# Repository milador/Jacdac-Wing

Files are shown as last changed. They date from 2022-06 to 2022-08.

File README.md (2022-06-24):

# Jacdaptor-FeatherWing

## Top View: 

<p align="center">
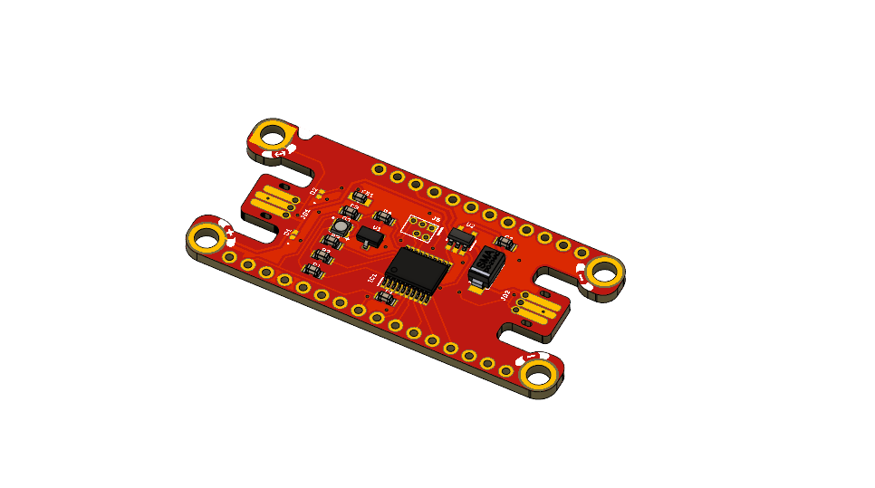
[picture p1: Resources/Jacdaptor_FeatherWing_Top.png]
Jacdaptor-FeatherWing Top

</p>

## Bottom View:

<p align="center">
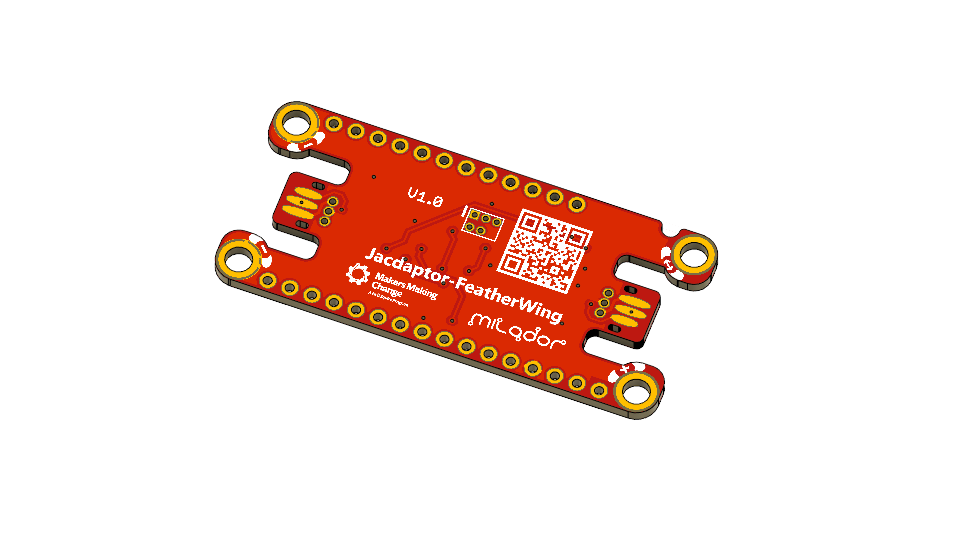
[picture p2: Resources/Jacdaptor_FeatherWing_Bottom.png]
Jacdaptor-FeatherWing Bottom

</p>

## Completed:

<p align="center">
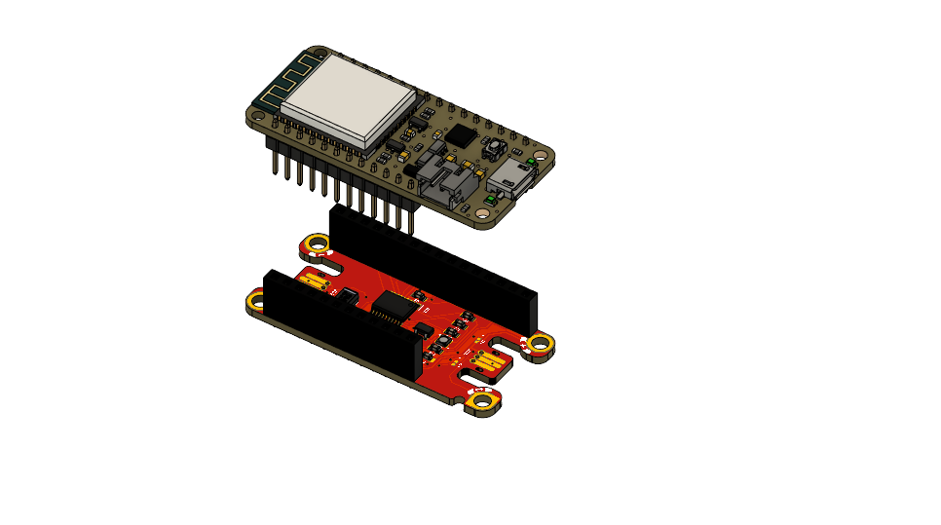
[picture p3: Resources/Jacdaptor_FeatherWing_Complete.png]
Jacdaptor FeatherWing Complete

</p>

<p align="center">
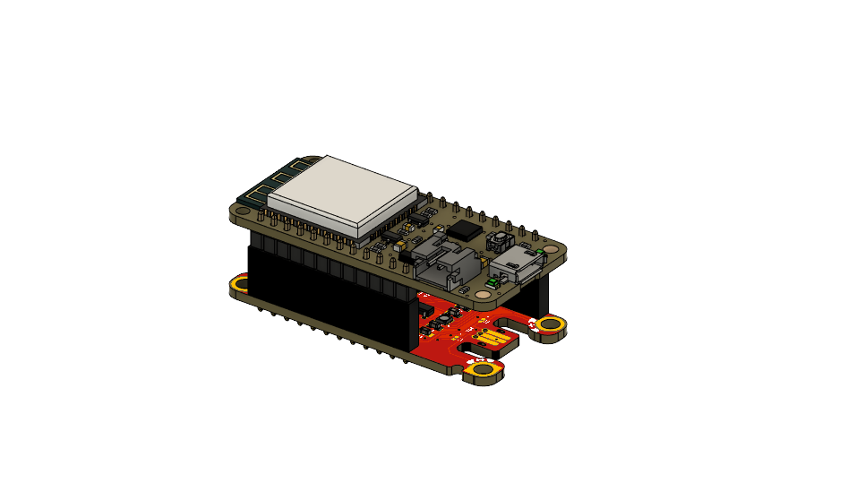
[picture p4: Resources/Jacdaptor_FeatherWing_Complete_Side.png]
Jacdaptor FeatherWing Complete Side

</p>

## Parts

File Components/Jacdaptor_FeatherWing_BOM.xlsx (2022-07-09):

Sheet: RevA
Index | Quantity | Item | Value | Digikey/Mouser/LCSC Part Number | Manufacturer Part Number | Description | Unit Price (CAD) | Total Price (CAD) | Link
1 | 2 | R1,R2 | 30R | C136965 | RT0603BRD0730RL | RES 30 OHM 1% 1/8W 0603 | 0.0344 | 0.0688 | https://lcsc.com/product-detail/Chip-span-style-background-color-ff0-Resistor-span-Surface-Mount_YAGEO-RT0603BRD0730RL_C136965.html
2 | 1 | R3 | 150R | C319859 | AR03BTCX1500 | RES 150 OHM 1% 1/8W 0603 | 0.037 | 0.037 | https://lcsc.com/product-detail/Chip-Resistor-Surface-Mount_Viking-Tech-AR03BTCX1500_C319859.html
3 | 1 | R4 | 220R | C318124 | AR03BTCX2200 | RES SMD 220 OHM 5% 1/8W 0603 | 0.029 | 0.029 | https://lcsc.com/product-detail/Chip-Resistor-Surface-Mount_Viking-Tech-AR03BTCX2200_C318124.html
4 | 1 | U1 | BAT54S,235 | C503463 | BAT54S,235 | DIODE ARRAY SCHOTTKY 30V SOT23 | 0.03 | 0.03 | https://lcsc.com/product-detail/Pre-ordered-transistors_Nexperia-BAT54S-235_C503463.html
5 | 1 | U2 | STM32G030F6P6 | C724040 | STM32G030F6P6 | IC MCU 32BIT 32KB FLASH 20TSSOP | 0.98 | 0.98 | https://lcsc.com/product-detail/ST-Microelectronics_STMicroelectronics-STM32G030F6P6_C724040.html
6 | 1 | U3 | APL3511DBI | C351148 | APL3511DBI-TRG | SOT-23-5 POWER DISTRIBUTION | 0.3 | 0.3 | https://lcsc.com/product-detail/Power-Distribution-Switches_Anpec-Elec-APL3511DBI-TRG_C351148.html
7 | 2 | C1,C2 | 4.7uF | C342959 | C1608X7S1A475KT000E | CAP CER 4.7UF 10V X5R 0603 | 0.048 | 0.096 | https://lcsc.com/product-detail/Multilayer-Ceramic-Capacitors-MLCC-SMD-SMT_TDK-C1608X7S1A475KT000E_C342959.html
8 | 1 | C3 | 33pF | C519485 | CC0603FRNPO9BN330 | CAP CER 0603 33PF 50V ULTRA STAB | 0.0177 | 0.0177 | https://lcsc.com/product-detail/Multilayer-Ceramic-Capacitors-MLCC-SMD-SMT_YAGEO-CC0603FRNPO9BN330_C519485.html
9 | 1 | FB1 | 800mA 1kR | C193411 | MPZ1608S102ATD25 | FERRITE BEAD 1 KOHM 0603 1LN | 0.028 | 0.028 | https://lcsc.com/product-detail/Ferrite-Beads_TDK-MPZ1608S102ATD25_C193411.html
10 | 2 | D1,D2 | RCLAMP0521P | C2827711 | RCLAMP0521P | TVS DIODE 5VWM 25VC SLP1006P2 | 0.0445 | 0.089 | https://lcsc.com/product-detail/ESD-Protection-Devices_TECH-PUBLIC-RCLAMP0521P_C2827711.html
11 | 1 | LED (D3) | RGB LED | 516-1795-1-ND /C97504 | HSMF-C114 | LED RGB DIFFUSED CHIP SMD | 2.63 | 2.63 | https://www.digikey.ca/en/products/detail/broadcom-limited/HSMF-C114/1235344 | https://lcsc.com/product-detail/Light-Emitting-Diodes-LED_Broadcom-Limited-HSMF-C114_C97504.html
12 | 1 | D4 | SCHOTTKY DIODE | C2480 | SS14 | SCHOTTKY DIODE | 0.0208 | 0.0208 | https://lcsc.com/product-detail/Schottky-Barrier-Diodes-SBD_MDD-Microdiode-Electronics-SS14_C2480.html
 |  |  |  |  |  |  | Total Price: | 4.3263

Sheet: RevB
Index | Quantity | Item | Value | Digikey/Mouser/LCSC Part Number | Manufacturer Part Number | Description | Unit Price (CAD) | Total Price (CAD) | Link
1 | 1 | R1 | 470R | C374403 | AR03BTC4700 | RES 470 OHM 0.1% 1/8W 0603 | 0.0316 | 0.0316 | https://lcsc.com/product-detail/Chip-Resistor-Surface-Mount_Viking-Tech-AR03BTC4700_C374403.html
2 | 1 | R3 | 150R | C319859 | AR03BTCX1500 | RES 150 OHM 1% 1/8W 0603 | 0.037 | 0.037 | https://lcsc.com/product-detail/Chip-Resistor-Surface-Mount_Viking-Tech-AR03BTCX1500_C319859.html
3 | 2 | R2,R4 | 220R | C318124 | AR03BTCX2200 | RES SMD 220 OHM 5% 1/8W 0603 | 0.029 | 0.058 | https://lcsc.com/product-detail/Chip-Resistor-Surface-Mount_Viking-Tech-AR03BTCX2200_C318124.html
4 | 1 | U1 | BAT54S,235 | C503463 | BAT54S,235 | DIODE ARRAY SCHOTTKY 30V SOT23 | 0.03 | 0.03 | https://lcsc.com/product-detail/Pre-ordered-transistors_Nexperia-BAT54S-235_C503463.html
5 | 1 | U2 | STM32G030F6P6 | C724040 | STM32G030F6P6 | IC MCU 32BIT 32KB FLASH 20TSSOP | 0.98 | 0.98 | https://lcsc.com/product-detail/ST-Microelectronics_STMicroelectronics-STM32G030F6P6_C724040.html
6 | 1 | U3 | APL3511DBI | C351148 | APL3511DBI-TRG | SOT-23-5 POWER DISTRIBUTION | 0.3 | 0.3 | https://lcsc.com/product-detail/Power-Distribution-Switches_Anpec-Elec-APL3511DBI-TRG_C351148.html
7 | 2 | C1,C2 | 4.7uF | C342959 | C1608X7S1A475KT000E | CAP CER 4.7UF 10V X5R 0603 | 0.048 | 0.096 | https://lcsc.com/product-detail/Multilayer-Ceramic-Capacitors-MLCC-SMD-SMT_TDK-C1608X7S1A475KT000E_C342959.html
8 | 1 | C3 | 33pF | C519485 | CC0603FRNPO9BN330 | CAP CER 0603 33PF 50V ULTRA STAB | 0.0177 | 0.0177 | https://lcsc.com/product-detail/Multilayer-Ceramic-Capacitors-MLCC-SMD-SMT_YAGEO-CC0603FRNPO9BN330_C519485.html
9 | 1 | FB1 | 800mA 1kR | C193411 | MPZ1608S102ATD25 | FERRITE BEAD 1 KOHM 0603 1LN | 0.028 | 0.028 | https://lcsc.com/product-detail/Ferrite-Beads_TDK-MPZ1608S102ATD25_C193411.html
10 | 2 | D1,D2 | RCLAMP0521P | C2827711 | RCLAMP0521P | TVS DIODE 5VWM 25VC SLP1006P2 | 0.0445 | 0.089 | https://lcsc.com/product-detail/ESD-Protection-Devices_TECH-PUBLIC-RCLAMP0521P_C2827711.html
11 | 1 | LED (D3) | RGB LED | C108793 | FM-B2020RGBA-HG | LED RGB CHIP SMD | 0.0289 | 0.0289 | https://lcsc.com/product-detail/Light-Emitting-Diodes-LED_Foshan-NationStar-Optoelectronics-FM-B2020RGBA-HG_C108793.html | https://lcsc.com/product-detail/Light-Emitting-Diodes-LED_Broadcom-Limited-HSMF-C114_C97504.html
12 | 1 | D4 | SCHOTTKY DIODE | C2480 | SS14 | SCHOTTKY DIODE | 0.0208 | 0.0208 | https://lcsc.com/product-detail/Schottky-Barrier-Diodes-SBD_MDD-Microdiode-Electronics-SS14_C2480.html
 |  |  |  |  |  |  | Total Price: | 1.717

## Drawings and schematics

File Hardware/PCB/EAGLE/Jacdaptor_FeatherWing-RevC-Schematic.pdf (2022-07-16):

A

A

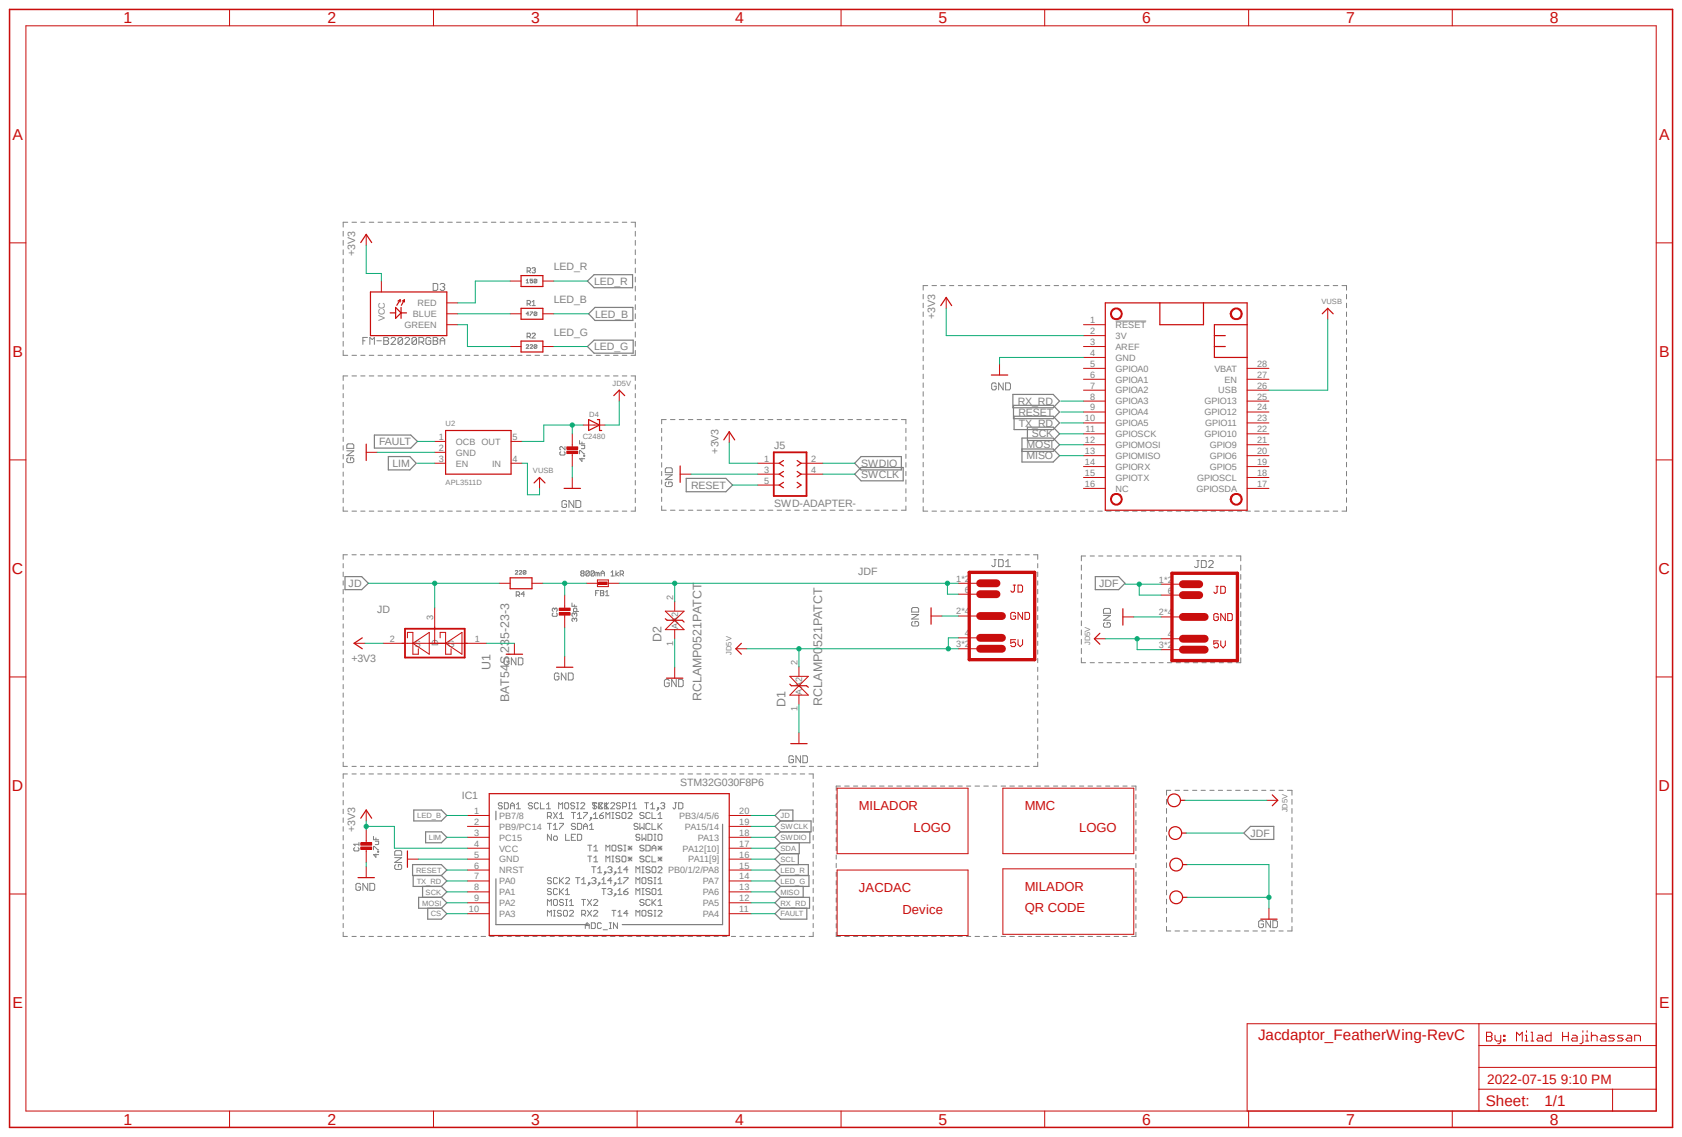
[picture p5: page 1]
+3V3 BAT54S,235-23-3 +3V3 +3V3 SWD-ADAPTER- +3V3 +3V3; VUSB JD⁵V; JD⁵V; VUSB; RCLAMP⁰⁵²¹PATCT; STM32G030F8P6 G; RESET 1; AREF 3; 27 GND 4; GPIO5; 19 GPIO6; 20 GPIO9; 21 GPIO10; 22 GPIO11; 23 GPIO12; 24 GPIO13; 25 GPIOA0 5; GPIOA1 6; GPIOA2 7; GPIOA3 8; GPIOA4 9; GPIOA5 10; GPIOMISO 13; GPIOMOSI 12; GPIORX 14; GPIOSCK 11; GPIOSCL; 18 GPIOSDA; 17 GPIOTX 15; USB; 26 VBAT; 6 GND 2; OCB 1; OUT; 4 U2APL3511D; BLUE GREEN; RED VCC; GND 5; NRST 6; VCC 4; JDF; LED_B; LED_G; LED_R; SCK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

LOGO MILADOR QR CODE

Jacdaptor_FeatherWing-RevC

Sheet:

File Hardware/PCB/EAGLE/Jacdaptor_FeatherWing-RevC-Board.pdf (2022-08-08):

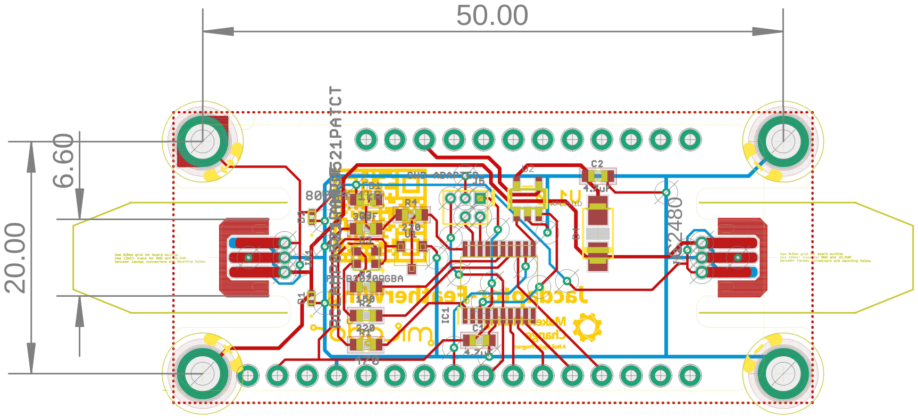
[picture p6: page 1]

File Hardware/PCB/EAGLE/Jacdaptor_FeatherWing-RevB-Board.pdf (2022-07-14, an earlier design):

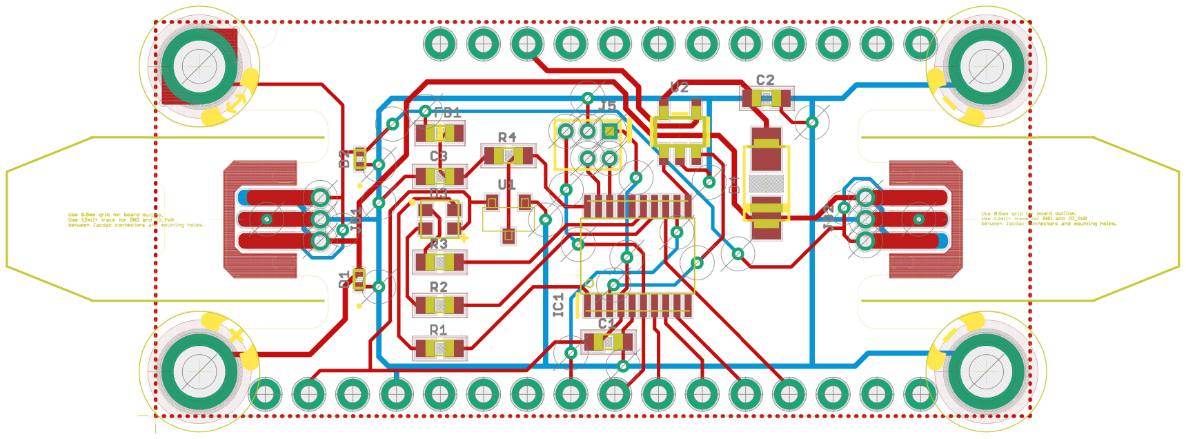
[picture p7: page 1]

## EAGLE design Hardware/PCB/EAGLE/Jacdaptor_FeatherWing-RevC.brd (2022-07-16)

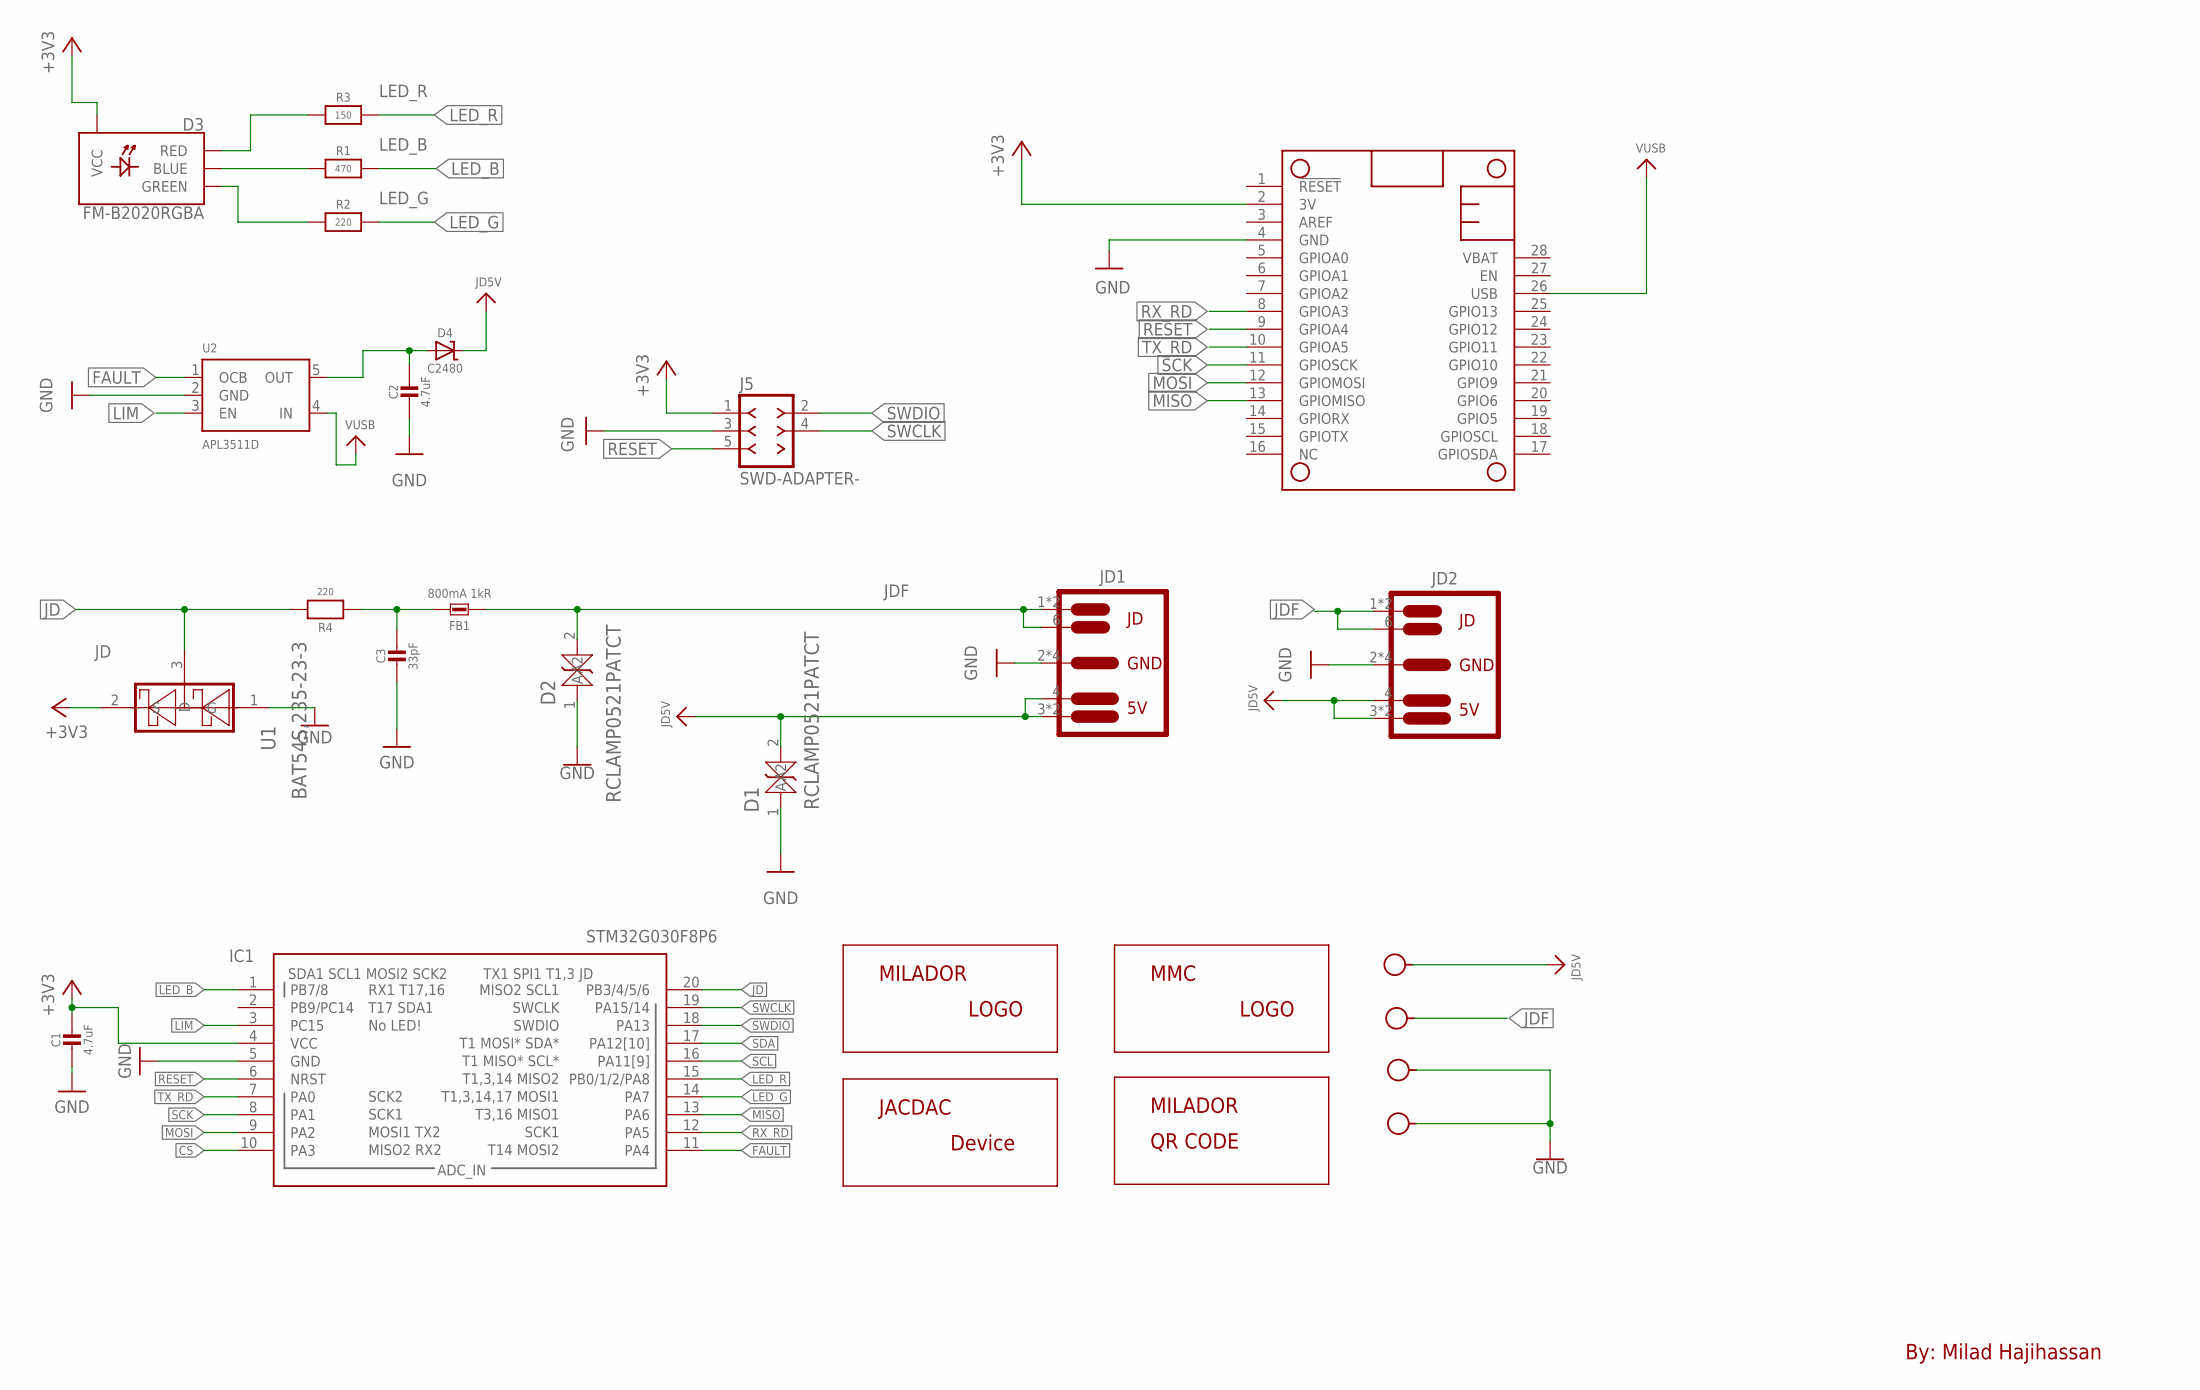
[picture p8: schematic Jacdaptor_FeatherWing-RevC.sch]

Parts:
C1, C2: 4.7uF; 0603
C3: 33pF; 0603
D1, D2: RCLAMP0521PATCT; DIODE-ZENER-0402
D3: FM-B2020RGBA; LED-RGB-2121
D4: C2480; DO214AC
FB1: 800mA 1kR; 0603-NO
IC1: STM32G030F8P6; SOP65P640X120-20N
J1: JACDAC-M3-DATA; M3-HOLE-DATA
J2: JACDAC-M3-PWR; M3-HOLE-PWR
J3, J4: JACDAC-M3-GND; M3-HOLE-GND
J5: SWD-ADAPTER-; SWD-ADAPTER
JD1, JD2: JACDAC-EDGE-INNIE; JD-EDGE-INNIE
LABEL_DEVICE: MILADOR-JACDAC-DEVICE-JACDAPTOR-WING; JACDAPTOR-FEATHERWING
LABEL_LOGO: MILADOR-LOGO-SM; MILADOR_LOGO2
LABEL_MMC: MMC_LOGO-XSM; MMC_X-SMALL_LOGO
LABEL_QR_CODE: MILADOR-QR-CODE-JACDAC-FEATHERWING; MILADOR_QR_JACDAC_FEATHERWING
MS1: ADAFRUIT_FEATHERWING_NODIM; ADAFRUIT_FEATHERWING_DIM
R1: 470; 0603
R2, R4: 220; 0603
R3: 150; 0603
U1: BAT54S,235-23-3; SOT23-3
U2: APL3511D; SOT23-5

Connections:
+3V3: C1.1, D3.PLUS (VCC), IC1.4 (VCC), J5.1 (VCC_1), MS1.2 (3V), U1.2 (S)
CS: IC1.10 (PA3)
FAULT: IC1.11 (PA4), U2.1 (OCB)
GND: C1.2, C2.2, C3.2, D1.1 (A), D2.1 (A), IC1.5 (GND), J3.H, J4.H, J5.3 (GND_3), JD1.2 (1), JD1.5 (1), JD1.P$2 (1), JD1.P$4 (1), JD2.2 (1), JD2.5 (1), JD2.P$2 (1), JD2.P$4 (1), MS1.4 (GND), U1.1 (G), U2.2 (GND)
JD: IC1.20 (PB3/4/5/6), R4.2, U1.3 (D)
JD5V: D1.2 (A2), D4.C, J2.H, JD1.3, JD1.4, JD1.P$1 (3), JD2.3, JD2.4, JD2.P$1 (3)
JDF: D2.2 (A2), FB1.2, J1.H, JD1.1 (2), JD1.6, JD1.P$3 (2), JD2.1 (2), JD2.6, JD2.P$3 (2)
LED_B: IC1.1 (PB7/8), R1.2
LED_G: IC1.14 (PA7), R2.2
LED_R: IC1.15 (PB0/1/2/PA8), R3.2
LIM: IC1.3 (PC15), U2.3 (EN)
MISO: IC1.13 (PA6), MS1.13 (GPIOMISO)
MOSI: IC1.9 (PA2), MS1.12 (GPIOMOSI)
unnamed: D3.B- (BLUE), R1.1
unnamed: D3.G- (GREEN), R2.1
unnamed: D3.R- (RED), R3.1
unnamed: C3.1, FB1.1, R4.1
OUT: C2.1, D4.A, U2.5 (OUT)
RESET: IC1.6 (NRST), J5.5 (RESET_5), MS1.9 (GPIOA4)
RX_RD: IC1.12 (PA5), MS1.8 (GPIOA3)
SCK: IC1.8 (PA1), MS1.11 (GPIOSCK)
SCL: IC1.16 (PA11[9])
SDA: IC1.17 (PA12[10])
SWCLK: IC1.19 (PA15/14), J5.4 (SWCLK_4)
SWDIO: IC1.18 (PA13), J5.2 (SWDIO_2)
TX_RD: IC1.7 (PA0), MS1.10 (GPIOA5)
VUSB: MS1.26 (USB), U2.4 (IN)

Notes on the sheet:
By: Milad Hajihassan

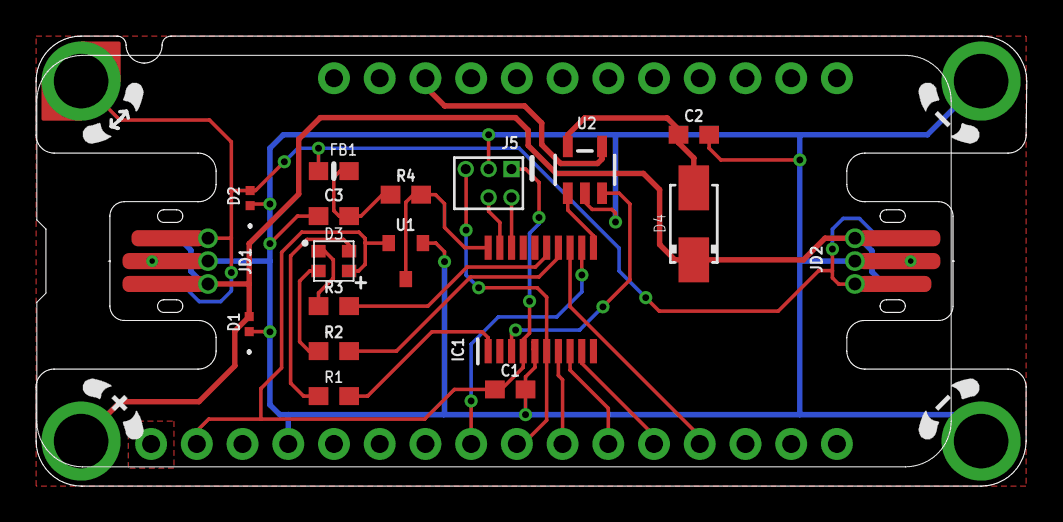
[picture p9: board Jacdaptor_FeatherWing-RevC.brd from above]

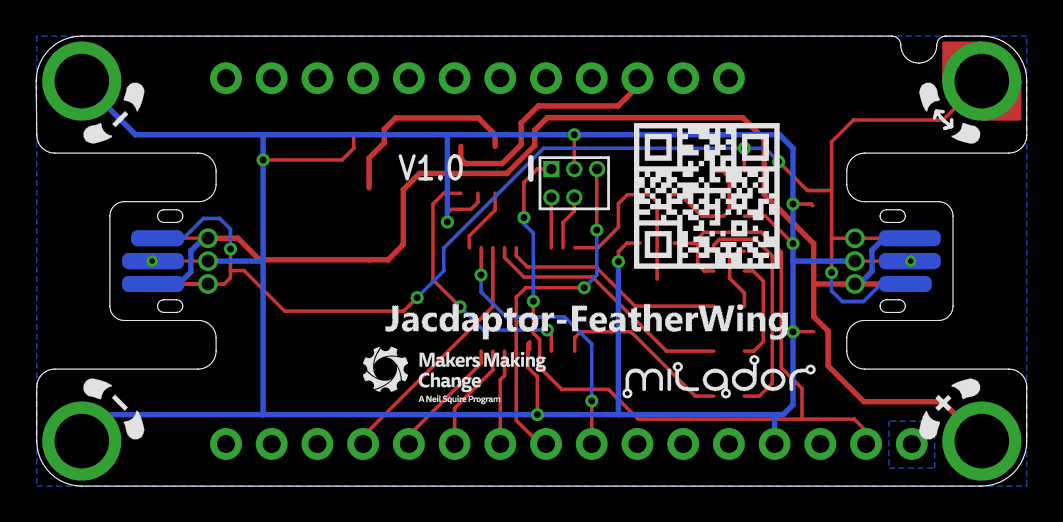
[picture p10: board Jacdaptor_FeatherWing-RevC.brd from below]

Board: 2 copper layers, 55.0 x 25.0 mm, 27 parts (4 on the bottom side), 24 nets.

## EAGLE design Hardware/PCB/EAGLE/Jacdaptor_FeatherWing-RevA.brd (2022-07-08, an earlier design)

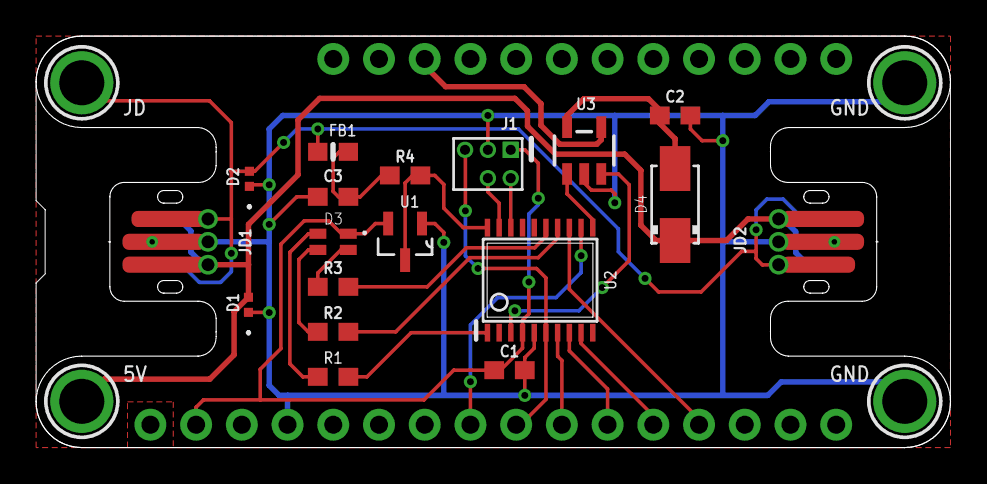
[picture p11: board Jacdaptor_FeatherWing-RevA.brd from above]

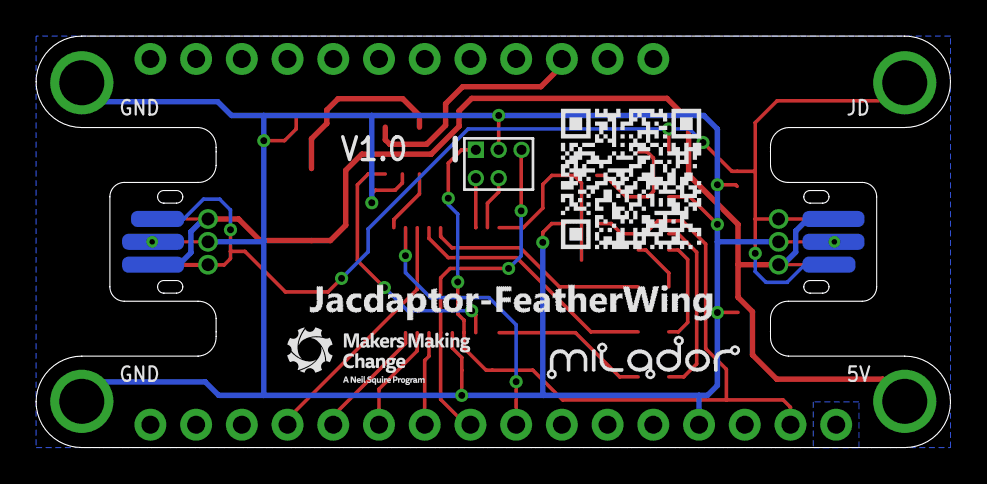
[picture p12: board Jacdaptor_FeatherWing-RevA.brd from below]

Board: 2 copper layers, 50.8 x 22.9 mm, 27 parts (4 on the bottom side), 24 nets.

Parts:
C1, C2: 4.7uF; 0603
C3: 33pF; 0603
D1, D2: DIODE-ZENER-AA-RCLAMP0521PATCT; DIODE-ZENER-0402
D3: LED-HSMF-C114; DIOSC160X150X35-4N
D4: C2480; DO214AC
FB1: 800mA 1kR; 0603-NO
H1, H2, H3, H4: MOUNTINGHOLE2.5; MOUNTINGHOLE_2.5_PLATED
J1: SWD-ADAPTER-; SWD-ADAPTER
JD1, JD2: JACDAC-EDGE-INNIE; JD-EDGE-INNIE
LABEL_DEVICE: MILADOR-JACDAC-DEVICE-JACDAPTOR-WING; JACDAPTOR-FEATHERWING
LABEL_LOGO: MILADOR-LOGO-SM; MILADOR_LOGO2
LABEL_MMC: MMC_LOGO-XSM; MMC_X-SMALL_LOGO
LABEL_QR_CODE: MILADOR-QR-CODE-JACDAC-FEATHERWING; MILADOR_QR_JACDAC_FEATHERWING
MS1: ADAFRUIT_FEATHERWING_NODIM; ADAFRUIT_FEATHERWING_DIM
R1, R2: 30; 0603
R3: 150; 0603
R4: 220; 0603
U1: BAT54S,235; SOT23-3
U2: STM32G030F6P6; TSSOP20
U3: APL3511D; SOT23-5

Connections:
+3V3: C1.1, D3.1, J1.1, MS1.2, U1.2, U2.4
FAULT: U2.11, U3.1
GND: C1.2, C2.2, C3.2, D1.1, D2.1, H3.P$1, H4.P$1, J1.3, JD1.2, JD1.5, JD1.P$2, JD1.P$4, JD2.2, JD2.5, JD2.P$2, JD2.P$4, MS1.4, U1.1, U2.5, U3.2
JD: R4.2, U1.3, U2.20
JD5V: D1.2, D4.C, H1.P$1, JD1.3, JD1.4, JD1.P$1, JD2.3, JD2.4, JD2.P$1
JDF: D2.2, FB1.2, H2.P$1, JD1.1, JD1.6, JD1.P$3, JD2.1, JD2.6, JD2.P$3
LED_B: R1.2, U2.1
LED_G: R2.2, U2.14
LED_R: R3.2, U2.15
LIM: U2.3, U3.3
MISO: MS1.13, U2.13
MOSI: MS1.12, U2.9
unnamed: D3.4, R1.1
unnamed: D3.3, R2.1
unnamed: D3.2, R3.1
unnamed: C3.1, FB1.1, R4.1
OUT: C2.1, D4.A, U3.5
RESET: J1.5, MS1.9, U2.6
RX_RD: MS1.8, U2.12
SCK: MS1.11, U2.8
SWCLK: J1.4, U2.19
SWDIO: J1.2, U2.18
TX_RD: MS1.10, U2.7
VUSB: MS1.26, U3.4

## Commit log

2022-06-24 Added EAGLE Design files
    [Jacdaptor_FeatherWing.brd, Jacdaptor_FeatherWing.sch]
2022-07-07 Updated design
    [Jacdaptor_FeatherWing.brd, Jacdaptor_FeatherWing.sch]
2022-07-09 Updated RevB
    [Jacdaptor_FeatherWing-RevA.brd, Jacdaptor_FeatherWing-RevB.brd, Jacdaptor_FeatherWing.brd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]
2022-07-14 Updated design RevB
    [Jacdaptor_FeatherWing-RevB.brd]
2022-07-16 Added RevC
    [Jacdaptor_FeatherWing-RevC.brd, Jacdaptor_FeatherWing-RevC.sch]

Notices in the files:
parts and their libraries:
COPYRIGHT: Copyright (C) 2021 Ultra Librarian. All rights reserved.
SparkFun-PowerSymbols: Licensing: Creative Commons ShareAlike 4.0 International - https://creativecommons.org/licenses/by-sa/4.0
